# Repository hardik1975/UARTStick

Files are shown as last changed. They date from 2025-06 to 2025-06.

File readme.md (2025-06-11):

<!-- [![IMAGE ALT TEXT HERE](https://img.youtube.com/vi/YTt_m9mckV0/0.jpg)](https://www.youtube.com/watch?v=YTt_m9mckV0) -->


diy-electronics

<be>

"Buy Me A Coffee" (https://buymeacoffee.com/hardikseth)

# UART Stick 

<!-- ## 📌 Table of Contents

- [Overview](#-overview)
- [Features](#-features)
- [Specifications](#-specifications)
- [Getting Started](#-getting-started)
- [Use Cases](#-use-cases)
- [Installation](#-installation)
- [Repository Structure](#-repository-structure)
- [License](#-license)
- [Buy or Build](#-buy-or-build)
- [Contributing](#-contributing)
- [Contact](#-contact) -->

## Overview

Say hello to UART Stick — a micro-sized, Arduino-compatible USB to UART converter designed for makers, tinkerers, and embedded developers.

Unlike bulky boards, UART Stick is tiny, hassle-free, and packed with all the essential features you need to program your microcontrollers or read serial data — all while fitting directly into your USB port.

Screen 4032x3024
<!-- ![IMG_6009](https://github.com/user-attachments/assets/4426eec0-49e4-4b4b-a8c7-a0a5a33d2cde) -->

## 🛒 Get Yours 

Fill out the [**Order Form**](https://docs.google.com/forms/d/e/1FAIpQLScuvlHv1w9dNxcGCHg3nWeYM4Ih8bzRdD5PpWKtMh8NcgmPcg/viewform?usp=header) to grab your UART Stick today!

<!-- Choose from two versions via our [**Order Form**](#): -->

Choose from two versions:

1. **DIY Kit** – Includes a bare PCB, CH340G IC, resistor, capacitor, ESD diode, and USB connector.  
  A great choice for learning and hands-on soldering practice!

2. **Fully Assembled** – Ready to use out of the box. Just plug it into your USB port and start programming!

Perfect for makers, students, and embedded devs — just plug and start building!

## Features

1. Compact Design – As small as a USB plug, perfect for on-the-go prototyping.
2. No Wires Needed – Built-in USB edge connector for direct plug-and-play.
3. CH340G Based – Reliable and widely supported USB-to-Serial IC.
4.  Open Source – Always will be. Hack it, mod it, or build your own.
5. Arduino-Compatible – Program boards via Arduino IDE effortlessly.
6. On-Board LEDs – Power, RX, and TX LEDs for easier debugging and status indication. 

## Specifications 

| Parameter | Value |
|---|---|
| IC | CH340G |
| USB Connector | Edge-mounted USB-A |
| Operating Voltage| 5V |
| Logic Level | 3.3V or 5V |
| Board Size | 52.25mm x 12mm |

## Getting Started

### What You’ll Need

1. Arduino IDE (or any serial monitor)
2. UART Stick
3. USB port
4. Jumper Wires

### Steps to Use

1. **Connect to Your Target Device**  
   Wire the UART Stick to your microcontroller or module as follows:

   | UART Stick Pin | Target Device     |
   |----------------|-------------------|
   | VCC            | 3.3V or 5V        |
   | RX             | TX                |
   | TX             | RX                |
   | GND            | GND               |

2. **Plug in the UART Stick**  
   Insert it directly into your computer’s USB port — no cables needed thanks to the edge USB connector.  

3. **Select the Correct COM Port**  
   Select correct COM port in Arduino IDE or your preferred serial tool.

4. **Start Communicating**

    - Upload code to your microcontroller
    - Or monitor serial data
    - Or send/receive commands

## 🔧 Use Cases

Here’s how UART Stick fits into your daily prototyping and debugging workflow:

1. **Flashing Firmware**  
  Upload code to microcontrollers like Arduino, ESP32, STM32, or ATmega-based boards with ease.

2. **Debugging Sensors & Modules**  
  View real-time data or debug sensor output via Serial Monitor.

3. **Reading BLE Data**  
  Communicate with BLE modules like HM-10 or HC-05/06 to send and receive wireless serial data.

4. **General UART Communication**  
  Interface with any device that speaks UART — from GPS modules to embedded Linux boards (like Raspberry Pi’s UART GPIOs).

5. **Serial Console Access**  
  Open terminal access to headless boards or dev kits, especially useful for bootloaders, Linux boards, or ESPs in flashing mode.

6. **Part of Your Embedded Toolbox**  
  A reliable companion for DIY projects, robotics, IoT devices, and lab debugging tasks.

## Contact

Made with ❤️ by Hardik

Have questions, feedback, or cool project ideas using the UART Stick?  
We’d love to hear from you!

- 💼 [LinkedIn](https://www.linkedin.com/in/hardik-seth-8687b7201) 
- 📺 [YouTube](https://www.youtube.com/@DIYwithHardik) 
- 📸 [Instagram](https://www.instagram.com/diywithhardik/) 
- 📧 [Email](mailto:hardikseth1975@gmail.com)

## Join Our WhatsApp Group 💬

Are you a maker, tinkerer, or electronics enthusiast?

Join our WhatsApp group to connect with like-minded people, share projects, get support, and behind the scenes!

👉 [**Click here to join the Community**](https://chat.whatsapp.com/JCH8m2oZNCG9Hrr31iBuLr)

## 📚 References

- 📄 [KiCAD Download Link](https://www.kicad.org/download/)  
- 📄 [CH340G Datasheet](https://static.efetividade.net/img/ch340g-datasheet-34852.pdf)   
- 📦 [USB Edge Connector Library](https://github.com/vasya-zh/PCB-Edge-USB-connector-KiCad-library)

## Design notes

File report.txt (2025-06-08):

Info: Processing symbol 'C1:Capacitor_SMD:C_0805_2012Metric_Pad1.18x1.45mm_HandSolder'.
Info: Processing symbol 'Y2:HC-49_U-S16000000ABJB:XTAL_HC49P488W43L1150T466H350'.
Info: Processing symbol 'C2:Capacitor_SMD:C_0805_2012Metric_Pad1.18x1.45mm_HandSolder'.
Info: Processing symbol 'U3:Package_TO_SOT_SMD:SOT-23-5'.
Info: Processing symbol 'C3:Capacitor_SMD:C_0805_2012Metric_Pad1.18x1.45mm_HandSolder'.
Info: Processing symbol 'U2:Package_TO_SOT_SMD:SOT-23-6'.
Info: Processing symbol 'C4:Capacitor_SMD:C_0805_2012Metric_Pad1.18x1.45mm_HandSolder'.
Info: Processing symbol 'U1:Package_SO:SOIC-16_3.9x9.9mm_P1.27mm'.
Info: Processing symbol 'C5:Capacitor_SMD:C_0805_2012Metric_Pad1.18x1.45mm_HandSolder'.
Info: Processing symbol 'R3:Resistor_SMD:R_0805_2012Metric_Pad1.20x1.40mm_HandSolder'.
Info: Processing symbol 'C6:Capacitor_SMD:C_0805_2012Metric_Pad1.18x1.45mm_HandSolder'.
Info: Processing symbol 'R2:Resistor_SMD:R_0805_2012Metric_Pad1.20x1.40mm_HandSolder'.
Info: Processing symbol 'D1:LED_SMD:LED_0805_2012Metric_Pad1.15x1.40mm_HandSolder'.
Info: Processing symbol 'R1:Resistor_SMD:R_0805_2012Metric_Pad1.20x1.40mm_HandSolder'.
Info: Processing symbol 'D2:LED_SMD:LED_0805_2012Metric_Pad1.15x1.40mm_HandSolder'.
Info: Processing symbol 'JP1:Connector_PinHeader_2.54mm:PinHeader_1x03_P2.54mm_Vertical'.
Info: Processing symbol 'D3:LED_SMD:LED_0805_2012Metric_Pad1.15x1.40mm_HandSolder'.
Info: Processing symbol 'J5:Connector_USB_PCB_Edge:USB_A_PCB_Edge_receptacle'.
Info: Processing symbol 'J1:Connector_PinHeader_2.54mm:PinHeader_1x03_P2.54mm_Vertical'.
Info: Processing symbol 'J4:Connector_PinHeader_2.54mm:PinHeader_1x03_P2.54mm_Vertical'.
Info: Processing symbol 'J3:Connector_PinHeader_2.54mm:PinHeader_1x04_P2.54mm_Horizontal'.
Add J3 (footprint 'Connector_PinHeader_2.54mm:PinHeader_1x04_P2.54mm_Horizontal').
Add J1 (footprint 'Connector_PinHeader_2.54mm:PinHeader_1x03_P2.54mm_Vertical').
Add J4 (footprint 'Connector_PinHeader_2.54mm:PinHeader_1x03_P2.54mm_Vertical').
Add D3 (footprint 'LED_SMD:LED_0805_2012Metric_Pad1.15x1.40mm_HandSolder').
Add J5 (footprint 'Connector_USB_PCB_Edge:USB_A_PCB_Edge_receptacle').
Add D2 (footprint 'LED_SMD:LED_0805_2012Metric_Pad1.15x1.40mm_HandSolder').
Add JP1 (footprint 'Connector_PinHeader_2.54mm:PinHeader_1x03_P2.54mm_Vertical').
Add D1 (footprint 'LED_SMD:LED_0805_2012Metric_Pad1.15x1.40mm_HandSolder').
Add R1 (footprint 'Resistor_SMD:R_0805_2012Metric_Pad1.20x1.40mm_HandSolder').
Add C6 (footprint 'Capacitor_SMD:C_0805_2012Metric_Pad1.18x1.45mm_HandSolder').
Add R2 (footprint 'Resistor_SMD:R_0805_2012Metric_Pad1.20x1.40mm_HandSolder').
Add C5 (footprint 'Capacitor_SMD:C_0805_2012Metric_Pad1.18x1.45mm_HandSolder').
Add R3 (footprint 'Resistor_SMD:R_0805_2012Metric_Pad1.20x1.40mm_HandSolder').
Add C4 (footprint 'Capacitor_SMD:C_0805_2012Metric_Pad1.18x1.45mm_HandSolder').
Add U1 (footprint 'Package_SO:SOIC-16_3.9x9.9mm_P1.27mm').
Add C3 (footprint 'Capacitor_SMD:C_0805_2012Metric_Pad1.18x1.45mm_HandSolder').
Add U2 (footprint 'Package_TO_SOT_SMD:SOT-23-6').
Add C2 (footprint 'Capacitor_SMD:C_0805_2012Metric_Pad1.18x1.45mm_HandSolder').
Add U3 (footprint 'Package_TO_SOT_SMD:SOT-23-5').
Add C1 (footprint 'Capacitor_SMD:C_0805_2012Metric_Pad1.18x1.45mm_HandSolder').
Add Y2 (footprint 'HC-49_U-S16000000ABJB:XTAL_HC49P488W43L1150T466H350').

Info: Total warnings: 0, errors: 0.

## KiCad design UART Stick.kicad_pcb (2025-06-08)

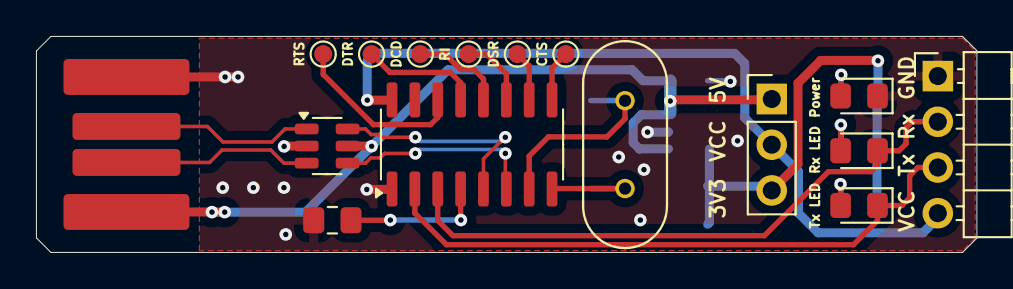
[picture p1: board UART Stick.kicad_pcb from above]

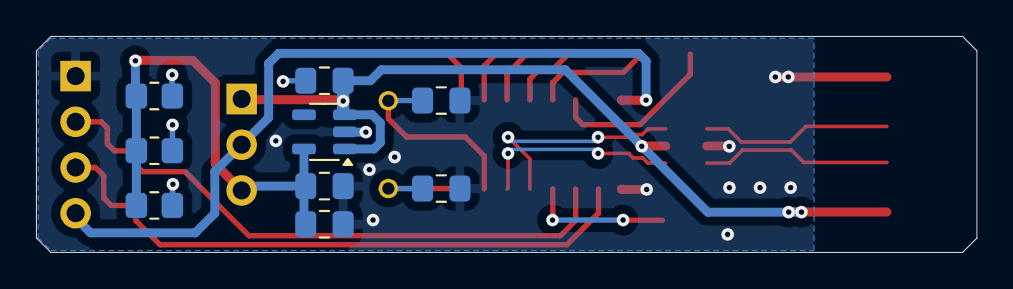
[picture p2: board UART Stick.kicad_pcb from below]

Board: 2 copper layers, 52.3 x 12.0 mm, 25 parts (9 on the bottom side), 22 nets.

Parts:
C1, C2: 22pF; C_0805_2012Metric_Pad1.18x1.45mm_HandSolder
C3: 10nF; C_0805_2012Metric_Pad1.18x1.45mm_HandSolder
C4, C6: 10uF; C_0805_2012Metric_Pad1.18x1.45mm_HandSolder
C5: 100nF; C_0805_2012Metric_Pad1.18x1.45mm_HandSolder
CTS: TestPoint; TestPoint_Pad_D1.0mm
D1: Tx_LED; LED_0805_2012Metric_Pad1.15x1.40mm_HandSolder
D2: Rx_LED; LED_0805_2012Metric_Pad1.15x1.40mm_HandSolder
D3: Power Led; LED_0805_2012Metric_Pad1.15x1.40mm_HandSolder
DCD: TestPoint; TestPoint_Pad_D1.0mm
DSR: TestPoint; TestPoint_Pad_D1.0mm
DTR: TestPoint; TestPoint_Pad_D1.0mm
J3: Conn_01x04_Pin; PinHeader_1x04_P2.54mm_Horizontal
J5: USB_A_PCB_Edge_receptacle
JP1: Jumper_3_Open; PinHeader_1x03_P2.54mm_Vertical
R1, R2, R3: 1k; R_0805_2012Metric_Pad1.20x1.40mm_HandSolder
RI: TestPoint; TestPoint_Pad_D1.0mm
RTS: TestPoint; TestPoint_Pad_D1.0mm
U1: CH340G; SOIC-16_3.9x9.9mm_P1.27mm
U2: USBLC6-2SC6; SOT-23-6
U3: SPX3819M5-L-3-3; SOT-23-5
Y2: HC-49_U-S16000000ABJB; XTAL_HC49P488W43L1150T466H350

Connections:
+3V3: C5.1, C6.1, JP1.3 (B), R1.1, R2.1, R3.1, U3.5 (OUT)
/USB_N: J5.2 (D-), U2.3 (I/O2)
/USB_P: J5.3 (D+), U2.1 (I/O1)
CH3_CTS: CTS.1, U1.9 (~CTS)
CH3_DCD: DCD.1, U1.12 (~DCD)
CH3_DSR: DSR.1, U1.10 (~DSR)
CH3_DTR: DTR.1, U1.13 (~DTR)
CH3_RI: RI.1, U1.11 (~RI)
CH3_RTS: RTS.1, U1.14 (~RTS)
CH3_Rx: D2.1 (K), J3.2, U1.3 (RXD)
CH3_Tx: D1.1 (K), J3.3, U1.2 (TXD)
GND: C1.2, C2.2, C3.2, C4.2, C5.2, C6.2, D3.1 (K), J3.1, J5.4 (GND), U1.1 (GND), U2.2 (GND), U3.2 (GND)
unnamed: D1.2 (A), R3.2
unnamed: D2.2 (A), R2.2
unnamed: D3.2 (A), R1.2
unnamed: C3.1, U1.4 (V3)
unnamed: C1.1, U1.7 (XI), Y2.1
unnamed: C2.1, U1.8 (XO), Y2.2
USB_D+: U1.5 (UD+), U2.6 (I/O1)
USB_D-: U1.6 (UD-), U2.4 (I/O2)
VBUS: C4.1, J5.1 (VBUS), JP1.1 (A), U2.5 (VBUS), U3.1 (IN), U3.3 (EN)
VCC: J3.4, JP1.2 (C), U1.16 (VCC)

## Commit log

2025-06-08 UART Stick - First commit
    [UART Stick.kicad_pcb, UART Stick.kicad_sch]
2025-06-09 Add UART Stick Image
2025-06-10 UART Stick image update
